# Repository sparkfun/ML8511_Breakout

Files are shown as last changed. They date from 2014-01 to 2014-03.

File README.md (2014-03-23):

ML8511 UV Sensor Breakout
=========================

ML8511 UV Sensor (https://www.sparkfun.com/products/12705)

[*ML8511 UV Sensor (SEN-12705)*](https://www.sparkfun.com/products/12705)

The ML8511 sensor detects ultraviolet light in the 280 to 390nm range.

Repository Contents
-------------------

* **/Firmware** - Example firmware for running the sensor
* **/Hardware** - All Eagle design files (.brd, .sch)
* **/Production** - Test bed files and production panel files
 
License Information
-------------------
The hardware is released under [Creative Commons ShareAlike 4.0 International](https://creativecommons.org/licenses/by-sa/4.0/).
The code is beerware; if you see me (or any other SparkFun employee) at the local, and you've found our code helpful, please buy us a round!

Distributed as-is; no warranty is given.

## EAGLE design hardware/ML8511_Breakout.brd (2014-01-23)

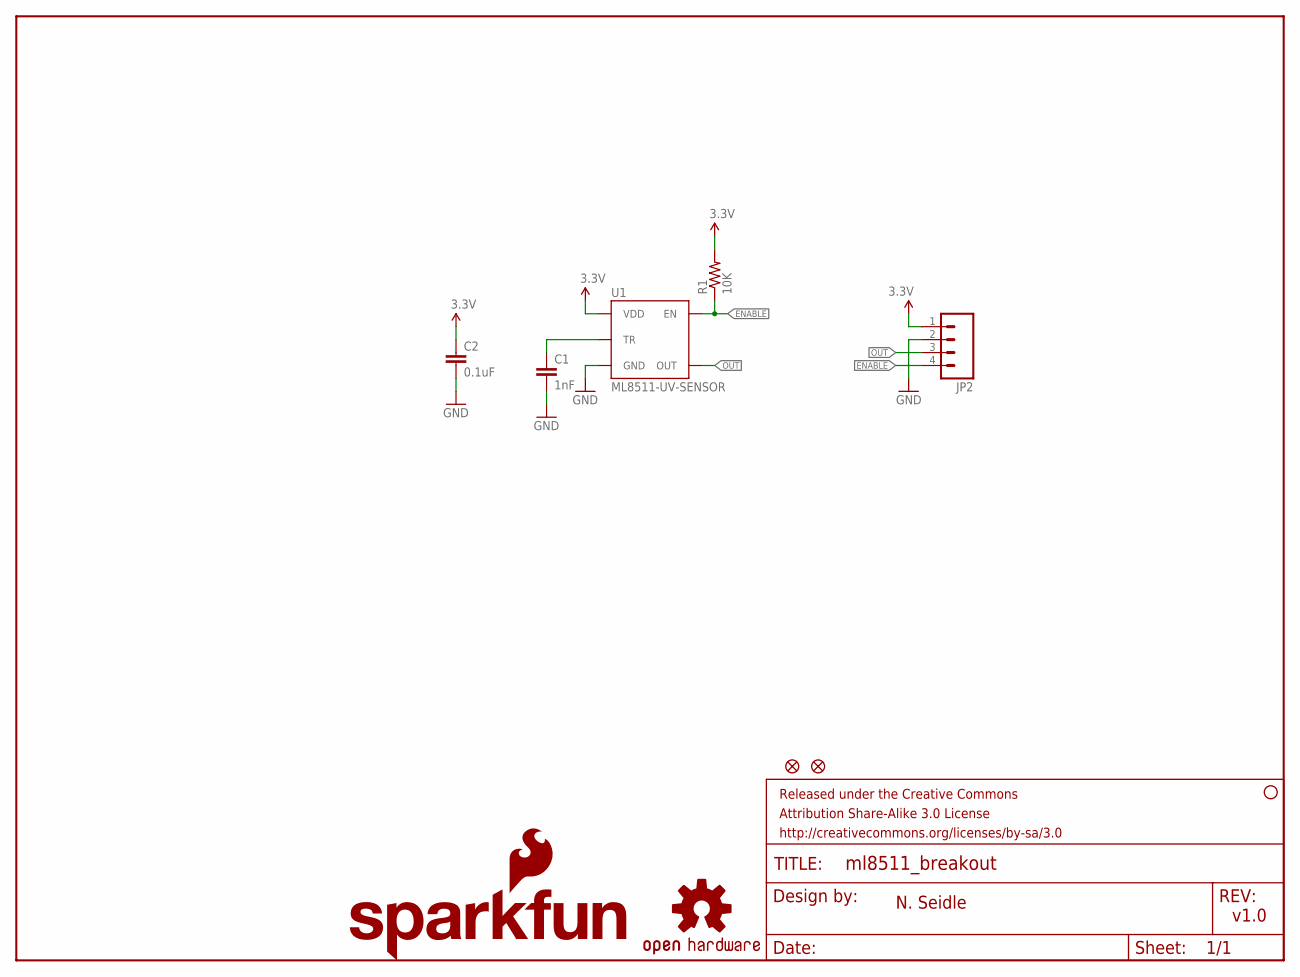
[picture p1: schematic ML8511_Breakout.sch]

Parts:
C1: 1nF; 0603-CAP
C2: 0.1uF; 0603-CAP
FID1, FID2: FIDUCIAL1X2; FIDUCIAL-1X2
FRAME2: FRAME-LETTER; CREATIVE_COMMONS
JP2: M04PTH; 1X04
LOGO2: OSHW-LOGOS; OSHW-LOGO-S
LOGO3: SFE_LOGO_FLAME.1_INCH; SFE_LOGO_FLAME_.1
LOGO4: SFE_LOGO_NAME.1_INCH; SFE_LOGO_NAME_.1
R1: 10K; 0603-RES
STANDOFF1: STAND-OFF
U1: ML8511-UV-SENSOR; ML8511

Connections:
3.3V: C2.1, JP2.1, R1.2, U1.7 (VDD)
ENABLE: JP2.4, R1.1, U1.4 (EN)
GND: C1.2, C2.2, JP2.2, U1.5 (GND)
unnamed: C1.1, U1.10 (TR)
OUT: JP2.3, U1.8 (OUT)

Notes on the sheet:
N. Seidle
v1.0

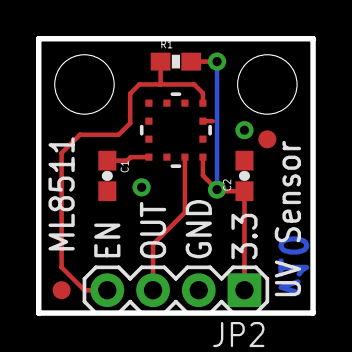
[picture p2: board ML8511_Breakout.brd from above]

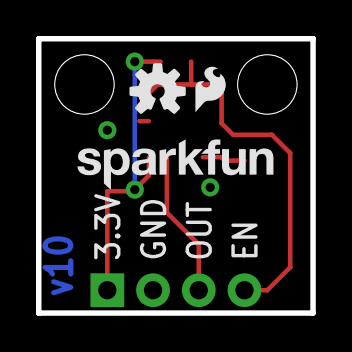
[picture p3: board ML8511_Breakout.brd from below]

Board: 2 copper layers, 15.2 x 15.2 mm, 13 parts (3 on the bottom side), 5 nets.

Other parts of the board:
STANDOFF2: STAND-OFF

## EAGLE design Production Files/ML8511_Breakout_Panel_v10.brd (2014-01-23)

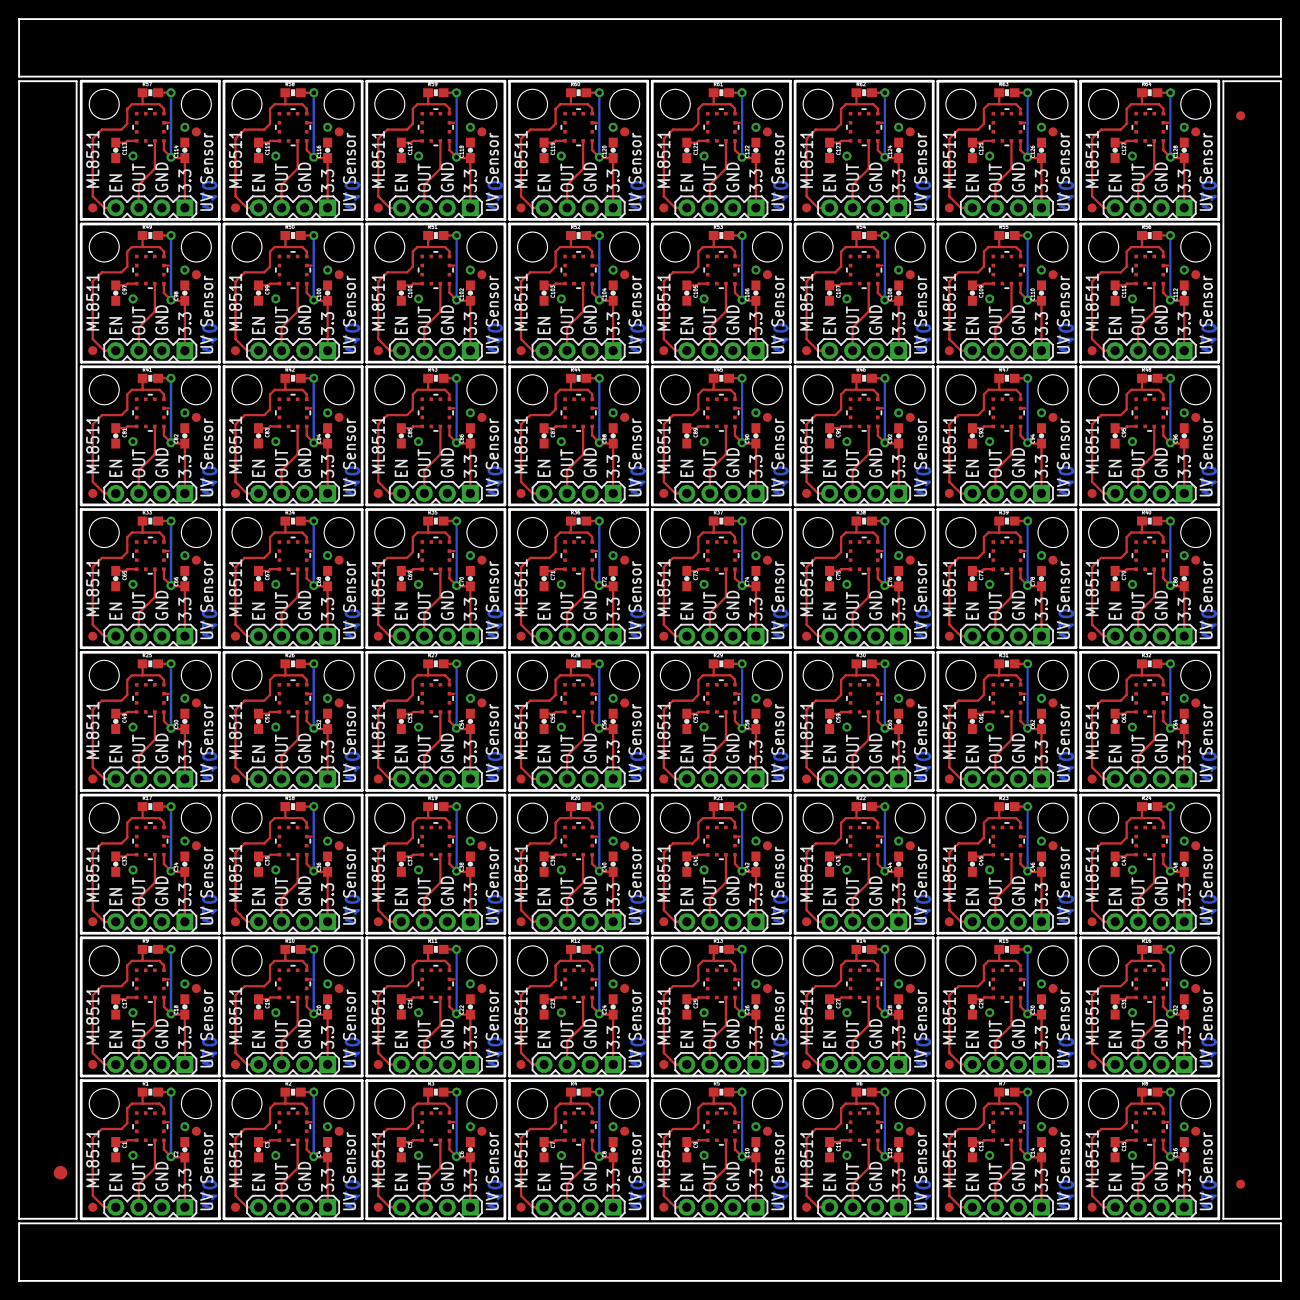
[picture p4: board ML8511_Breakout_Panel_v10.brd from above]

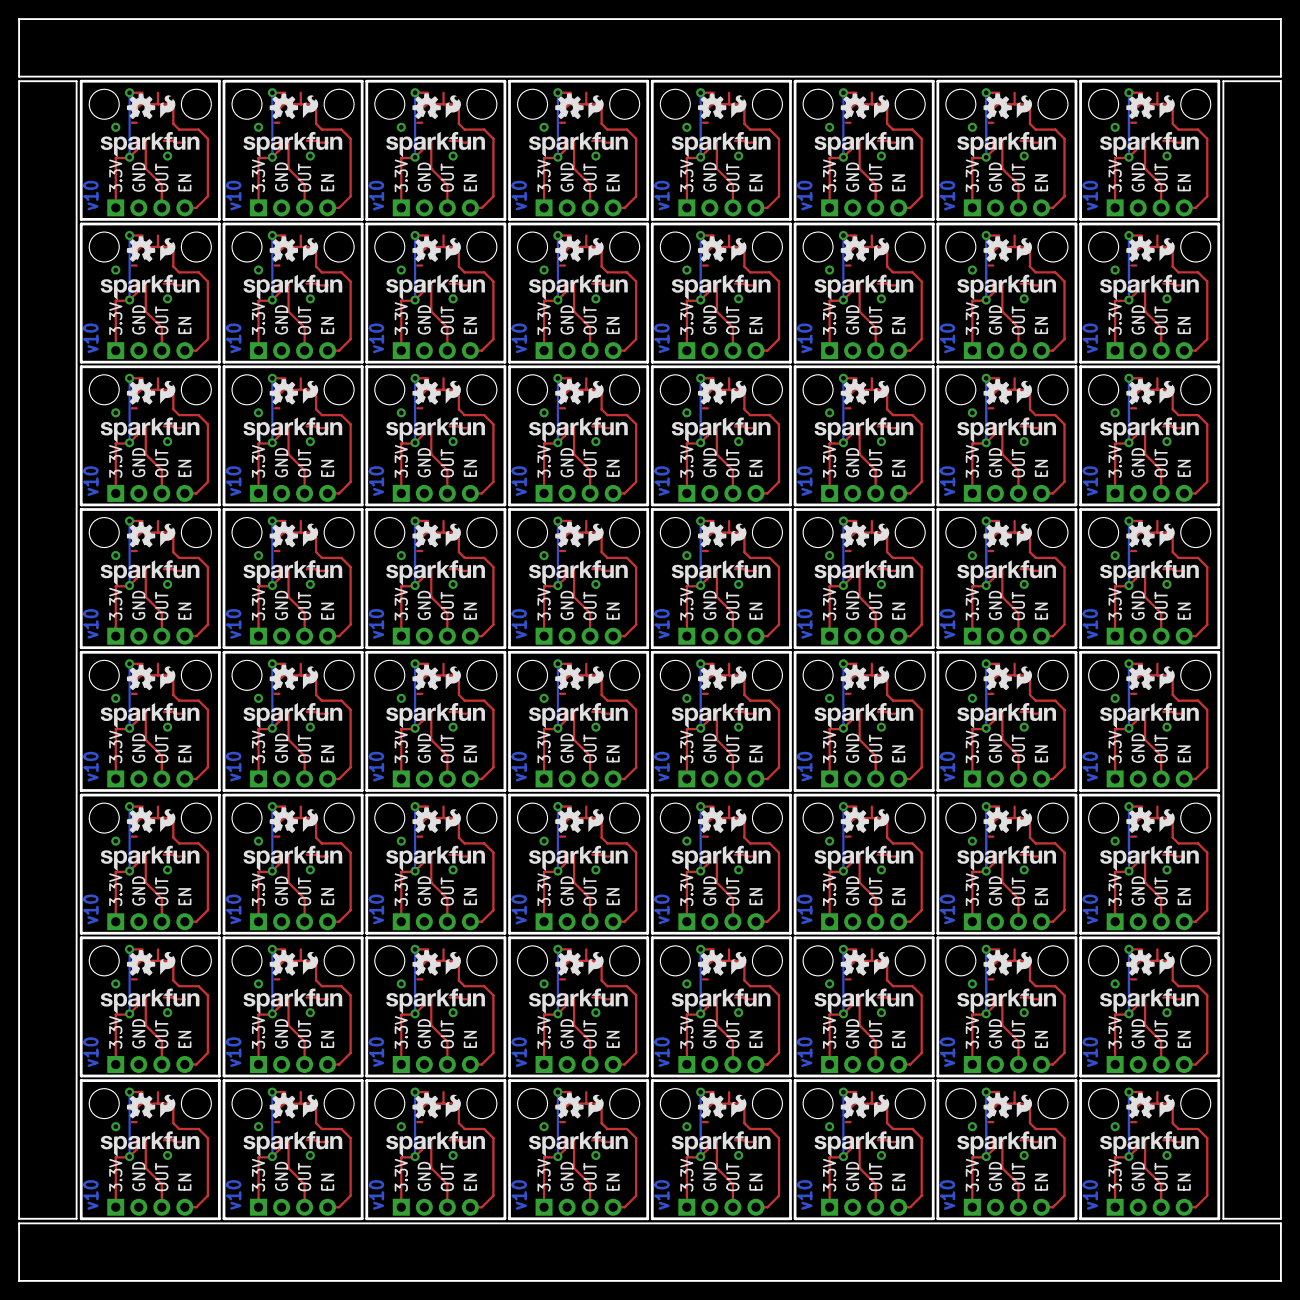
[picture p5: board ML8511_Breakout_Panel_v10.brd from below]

Board: 2 copper layers, 139.2 x 139.2 mm, 771 parts (192 on the bottom side), 320 nets.

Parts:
C1, C3, C5, C7, C9, C11, C13, C15, C17, C19, C21, C23, C25, C27, C29, C31, C33, C35, C37, C39, C41, C43, C45, C47, C49, C51, C53, C55, C57, C59, C61, C63, C65, C67, C69, C71, C73, C75, C77, C79, C81, C83, C85, C87, C89, C91, C93, C95, C97, C99, C101, C103, C105, C107, C109, C111, C113, C115, C117, C119, C121, C123, C125, C127: 1nF; 0603-CAP
C2, C4, C6, C8, C10, C12, C14, C16, C18, C20, C22, C24, C26, C28, C30, C32, C34, C36, C38, C40, C42, C44, C46, C48, C50, C52, C54, C56, C58, C60, C62, C64, C66, C68, C70, C72, C74, C76, C78, C80, C82, C84, C86, C88, C90, C92, C94, C96, C98, C100, C102, C104, C106, C108, C110, C112, C114, C116, C118, C120, C122, C124, C126, C128: 0.1uF; 0603-CAP
E$1: FIDUCIAL-1.5X3
E$4, E$5: FIDUCIAL-1X2
FID1, FID2, FID3, FID4, FID5, FID6, FID7, FID8, FID9, FID10, FID11, FID12, FID13, FID14, FID15, FID16, FID17, FID18, FID19, FID20, FID21, FID22, FID23, FID24, FID25, FID26, FID27, FID28, FID29, FID30, FID31, FID32, FID33, FID34, FID35, FID36, FID37, FID38, FID39, FID40, FID41, FID42, FID43, FID44, FID45, FID46, FID47, FID48, FID49, FID50, FID51, FID52, FID53, FID54, FID55, FID56, FID57, FID58, FID59, FID60, FID61, FID62, FID63, FID64, FID65, FID66, FID67, FID68, FID69, FID70, FID71, FID72, FID73, FID74, FID75, FID76, FID77, FID78, FID79, FID80, FID81, FID82, FID83, FID84, FID85, FID86, FID87, FID88, FID89, FID90, FID91, FID92, FID93, FID94, FID95, FID96, FID97, FID98, FID99, FID100, FID101, FID102, FID103, FID104, FID105, FID106, FID107, FID108, FID109, FID110, FID111, FID112, FID113, FID114, FID115, FID116, FID117, FID118, FID119, FID120, FID121, FID122, FID123, FID124, FID125, FID126, FID127, FID128: FIDUCIAL1X2; FIDUCIAL-1X2
JP1, JP2, JP3, JP4, JP5, JP6, JP7, JP8, JP9, JP10, JP11, JP12, JP13, JP14, JP15, JP16, JP17, JP18, JP19, JP20, JP21, JP22, JP23, JP24, JP25, JP26, JP27, JP28, JP29, JP30, JP31, JP32, JP33, JP34, JP35, JP36, JP37, JP38, JP39, JP40, JP41, JP42, JP43, JP44, JP45, JP46, JP47, JP48, JP49, JP50, JP51, JP52, JP53, JP54, JP55, JP56, JP57, JP58, JP59, JP60, JP61, JP62, JP63, JP64: 1X04
LOGO1, LOGO2, LOGO7, LOGO10, LOGO13, LOGO16, LOGO19, LOGO22, LOGO25, LOGO28, LOGO31, LOGO34, LOGO37, LOGO40, LOGO43, LOGO46, LOGO49, LOGO52, LOGO55, LOGO58, LOGO61, LOGO64, LOGO67, LOGO70, LOGO73, LOGO76, LOGO79, LOGO82, LOGO85, LOGO88, LOGO91, LOGO94, LOGO97, LOGO100, LOGO103, LOGO106, LOGO109, LOGO112, LOGO115, LOGO118, LOGO121, LOGO124, LOGO127, LOGO130, LOGO133, LOGO136, LOGO139, LOGO142, LOGO145, LOGO148, LOGO151, LOGO154, LOGO157, LOGO160, LOGO163, LOGO166, LOGO169, LOGO172, LOGO175, LOGO178, LOGO181, LOGO184, LOGO187, LOGO190: OSHW-LOGOS; OSHW-LOGO-S
LOGO3, LOGO5, LOGO8, LOGO11, LOGO14, LOGO17, LOGO20, LOGO23, LOGO26, LOGO29, LOGO32, LOGO35, LOGO38, LOGO41, LOGO44, LOGO47, LOGO50, LOGO53, LOGO56, LOGO59, LOGO62, LOGO65, LOGO68, LOGO71, LOGO74, LOGO77, LOGO80, LOGO83, LOGO86, LOGO89, LOGO92, LOGO95, LOGO98, LOGO101, LOGO104, LOGO107, LOGO110, LOGO113, LOGO116, LOGO119, LOGO122, LOGO125, LOGO128, LOGO131, LOGO134, LOGO137, LOGO140, LOGO143, LOGO146, LOGO149, LOGO152, LOGO155, LOGO158, LOGO161, LOGO164, LOGO167, LOGO170, LOGO173, LOGO176, LOGO179, LOGO182, LOGO185, LOGO188, LOGO191: SFE_LOGO_FLAME.1_INCH; SFE_LOGO_FLAME_.1
LOGO4, LOGO6, LOGO9, LOGO12, LOGO15, LOGO18, LOGO21, LOGO24, LOGO27, LOGO30, LOGO33, LOGO36, LOGO39, LOGO42, LOGO45, LOGO48, LOGO51, LOGO54, LOGO57, LOGO60, LOGO63, LOGO66, LOGO69, LOGO72, LOGO75, LOGO78, LOGO81, LOGO84, LOGO87, LOGO90, LOGO93, LOGO96, LOGO99, LOGO102, LOGO105, LOGO108, LOGO111, LOGO114, LOGO117, LOGO120, LOGO123, LOGO126, LOGO129, LOGO132, LOGO135, LOGO138, LOGO141, LOGO144, LOGO147, LOGO150, LOGO153, LOGO156, LOGO159, LOGO162, LOGO165, LOGO168, LOGO171, LOGO174, LOGO177, LOGO180, LOGO183, LOGO186, LOGO189, LOGO192: SFE_LOGO_NAME.1_INCH; SFE_LOGO_NAME_.1
R1, R2, R3, R4, R5, R6, R7, R8, R9, R10, R11, R12, R13, R14, R15, R16, R17, R18, R19, R20, R21, R22, R23, R24, R25, R26, R27, R28, R29, R30, R31, R32, R33, R34, R35, R36, R37, R38, R39, R40, R41, R42, R43, R44, R45, R46, R47, R48, R49, R50, R51, R52, R53, R54, R55, R56, R57, R58, R59, R60, R61, R62, R63, R64: 10K; 0603-RES
STANDOFF1, STANDOFF2, STANDOFF3, STANDOFF4, STANDOFF5, STANDOFF6, STANDOFF7, STANDOFF8, STANDOFF9, STANDOFF10, STANDOFF11, STANDOFF12, STANDOFF13, STANDOFF14, STANDOFF15, STANDOFF16, STANDOFF17, STANDOFF18, STANDOFF19, STANDOFF20, STANDOFF21, STANDOFF22, STANDOFF23, STANDOFF24, STANDOFF25, STANDOFF26, STANDOFF27, STANDOFF28, STANDOFF29, STANDOFF30, STANDOFF31, STANDOFF32, STANDOFF33, STANDOFF34, STANDOFF35, STANDOFF36, STANDOFF37, STANDOFF38, STANDOFF39, STANDOFF40, STANDOFF41, STANDOFF42, STANDOFF43, STANDOFF44, STANDOFF45, STANDOFF46, STANDOFF47, STANDOFF48, STANDOFF49, STANDOFF50, STANDOFF51, STANDOFF52, STANDOFF53, STANDOFF54, STANDOFF55, STANDOFF56, STANDOFF57, STANDOFF58, STANDOFF59, STANDOFF60, STANDOFF61, STANDOFF62, STANDOFF63, STANDOFF64, STANDOFF65, STANDOFF66, STANDOFF67, STANDOFF68, STANDOFF69, STANDOFF70, STANDOFF71, STANDOFF72, STANDOFF73, STANDOFF74, STANDOFF75, STANDOFF76, STANDOFF77, STANDOFF78, STANDOFF79, STANDOFF80, STANDOFF81, STANDOFF82, STANDOFF83, STANDOFF84, STANDOFF85, STANDOFF86, STANDOFF87, STANDOFF88, STANDOFF89, STANDOFF90, STANDOFF91, STANDOFF92, STANDOFF93, STANDOFF94, STANDOFF95, STANDOFF96, STANDOFF97, STANDOFF98, STANDOFF99, STANDOFF100, STANDOFF101, STANDOFF102, STANDOFF103, STANDOFF104, STANDOFF105, STANDOFF106, STANDOFF107, STANDOFF108, STANDOFF109, STANDOFF110, STANDOFF111, STANDOFF112, STANDOFF113, STANDOFF114, STANDOFF115, STANDOFF116, STANDOFF117, STANDOFF118, STANDOFF119, STANDOFF120, STANDOFF121, STANDOFF122, STANDOFF123, STANDOFF124, STANDOFF125, STANDOFF126, STANDOFF127, STANDOFF128: STAND-OFF
U1, U2, U3, U4, U5, U6, U7, U8, U9, U10, U11, U12, U13, U14, U15, U16, U17, U18, U19, U20, U21, U22, U23, U24, U25, U26, U27, U28, U29, U30, U31, U32, U33, U34, U35, U36, U37, U38, U39, U40, U41, U42, U43, U44, U45, U46, U47, U48, U49, U50, U51, U52, U53, U54, U55, U56, U57, U58, U59, U60, U61, U62, U63, U64: ML8511-UV-SENSOR; ML8511

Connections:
3.3V: C2.1, JP2.1, R1.2, U1.7
3.3V1: C4.1, JP1.1, R2.2, U2.7
3.3V2: C6.1, JP3.1, R3.2, U3.7
3.3V3: C8.1, JP4.1, R4.2, U4.7
3.3V4: C10.1, JP5.1, R5.2, U5.7
3.3V5: C12.1, JP6.1, R6.2, U6.7
3.3V6: C14.1, JP7.1, R7.2, U7.7
3.3V7: C16.1, JP8.1, R8.2, U8.7
3.3V8: C18.1, JP9.1, R9.2, U9.7
3.3V9: C20.1, JP10.1, R10.2, U10.7
3.3V10: C22.1, JP11.1, R11.2, U11.7
3.3V11: C24.1, JP12.1, R12.2, U12.7
3.3V12: C26.1, JP13.1, R13.2, U13.7
3.3V13: C28.1, JP14.1, R14.2, U14.7
3.3V14: C30.1, JP15.1, R15.2, U15.7
3.3V15: C32.1, JP16.1, R16.2, U16.7
3.3V16: C34.1, JP17.1, R17.2, U17.7
3.3V17: C36.1, JP18.1, R18.2, U18.7
3.3V18: C38.1, JP19.1, R19.2, U19.7
3.3V19: C40.1, JP20.1, R20.2, U20.7
3.3V20: C42.1, JP21.1, R21.2, U21.7
3.3V21: C44.1, JP22.1, R22.2, U22.7
3.3V22: C46.1, JP23.1, R23.2, U23.7
3.3V23: C48.1, JP24.1, R24.2, U24.7
3.3V24: C50.1, JP25.1, R25.2, U25.7
3.3V25: C52.1, JP26.1, R26.2, U26.7
3.3V26: C54.1, JP27.1, R27.2, U27.7
3.3V27: C56.1, JP28.1, R28.2, U28.7
3.3V28: C58.1, JP29.1, R29.2, U29.7
3.3V29: C60.1, JP30.1, R30.2, U30.7
3.3V30: C62.1, JP31.1, R31.2, U31.7
3.3V31: C64.1, JP32.1, R32.2, U32.7
3.3V32: C66.1, JP33.1, R33.2, U33.7
3.3V33: C68.1, JP34.1, R34.2, U34.7
3.3V34: C70.1, JP35.1, R35.2, U35.7
3.3V35: C72.1, JP36.1, R36.2, U36.7
3.3V36: C74.1, JP37.1, R37.2, U37.7
3.3V37: C76.1, JP38.1, R38.2, U38.7
3.3V38: C78.1, JP39.1, R39.2, U39.7
3.3V39: C80.1, JP40.1, R40.2, U40.7
3.3V40: C82.1, JP41.1, R41.2, U41.7
3.3V41: C84.1, JP42.1, R42.2, U42.7
3.3V42: C86.1, JP43.1, R43.2, U43.7
3.3V43: C88.1, JP44.1, R44.2, U44.7
3.3V44: C90.1, JP45.1, R45.2, U45.7
3.3V45: C92.1, JP46.1, R46.2, U46.7
3.3V46: C94.1, JP47.1, R47.2, U47.7
3.3V47: C96.1, JP48.1, R48.2, U48.7
3.3V48: C98.1, JP49.1, R49.2, U49.7
3.3V49: C100.1, JP50.1, R50.2, U50.7
3.3V50: C102.1, JP51.1, R51.2, U51.7
3.3V51: C104.1, JP52.1, R52.2, U52.7
3.3V52: C106.1, JP53.1, R53.2, U53.7
3.3V53: C108.1, JP54.1, R54.2, U54.7
3.3V54: C110.1, JP55.1, R55.2, U55.7
3.3V55: C112.1, JP56.1, R56.2, U56.7
3.3V56: C114.1, JP57.1, R57.2, U57.7
3.3V57: C116.1, JP58.1, R58.2, U58.7
3.3V58: C118.1, JP59.1, R59.2, U59.7
3.3V59: C120.1, JP60.1, R60.2, U60.7
3.3V60: C122.1, JP61.1, R61.2, U61.7
3.3V61: C124.1, JP62.1, R62.2, U62.7
3.3V62: C126.1, JP63.1, R63.2, U63.7
3.3V63: C128.1, JP64.1, R64.2, U64.7
ENABLE: JP2.4, R1.1, U1.4
ENABLE1: JP1.4, R2.1, U2.4
ENABLE2: JP3.4, R3.1, U3.4
ENABLE3: JP4.4, R4.1, U4.4
ENABLE4: JP5.4, R5.1, U5.4
ENABLE5: JP6.4, R6.1, U6.4
ENABLE6: JP7.4, R7.1, U7.4
ENABLE7: JP8.4, R8.1, U8.4
ENABLE8: JP9.4, R9.1, U9.4
ENABLE9: JP10.4, R10.1, U10.4
ENABLE10: JP11.4, R11.1, U11.4
ENABLE11: JP12.4, R12.1, U12.4
ENABLE12: JP13.4, R13.1, U13.4
ENABLE13: JP14.4, R14.1, U14.4
ENABLE14: JP15.4, R15.1, U15.4
ENABLE15: JP16.4, R16.1, U16.4
ENABLE16: JP17.4, R17.1, U17.4
ENABLE17: JP18.4, R18.1, U18.4
ENABLE18: JP19.4, R19.1, U19.4
ENABLE19: JP20.4, R20.1, U20.4
ENABLE20: JP21.4, R21.1, U21.4
ENABLE21: JP22.4, R22.1, U22.4
ENABLE22: JP23.4, R23.1, U23.4
ENABLE23: JP24.4, R24.1, U24.4
ENABLE24: JP25.4, R25.1, U25.4
ENABLE25: JP26.4, R26.1, U26.4
ENABLE26: JP27.4, R27.1, U27.4
ENABLE27: JP28.4, R28.1, U28.4
ENABLE28: JP29.4, R29.1, U29.4
ENABLE29: JP30.4, R30.1, U30.4
ENABLE30: JP31.4, R31.1, U31.4
ENABLE31: JP32.4, R32.1, U32.4
ENABLE32: JP33.4, R33.1, U33.4
ENABLE33: JP34.4, R34.1, U34.4
ENABLE34: JP35.4, R35.1, U35.4
ENABLE35: JP36.4, R36.1, U36.4
ENABLE36: JP37.4, R37.1, U37.4
ENABLE37: JP38.4, R38.1, U38.4
ENABLE38: JP39.4, R39.1, U39.4
ENABLE39: JP40.4, R40.1, U40.4
ENABLE40: JP41.4, R41.1, U41.4
ENABLE41: JP42.4, R42.1, U42.4
ENABLE42: JP43.4, R43.1, U43.4
ENABLE43: JP44.4, R44.1, U44.4
ENABLE44: JP45.4, R45.1, U45.4
ENABLE45: JP46.4, R46.1, U46.4
ENABLE46: JP47.4, R47.1, U47.4
ENABLE47: JP48.4, R48.1, U48.4
ENABLE48: JP49.4, R49.1, U49.4
ENABLE49: JP50.4, R50.1, U50.4
ENABLE50: JP51.4, R51.1, U51.4
ENABLE51: JP52.4, R52.1, U52.4
ENABLE52: JP53.4, R53.1, U53.4
ENABLE53: JP54.4, R54.1, U54.4
ENABLE54: JP55.4, R55.1, U55.4
ENABLE55: JP56.4, R56.1, U56.4
ENABLE56: JP57.4, R57.1, U57.4
ENABLE57: JP58.4, R58.1, U58.4
ENABLE58: JP59.4, R59.1, U59.4
ENABLE59: JP60.4, R60.1, U60.4
ENABLE60: JP61.4, R61.1, U61.4
ENABLE61: JP62.4, R62.1, U62.4
ENABLE62: JP63.4, R63.1, U63.4
ENABLE63: JP64.4, R64.1, U64.4
GND: C1.2, C2.2, JP2.2, U1.5
GND1: C3.2, C4.2, JP1.2, U2.5
GND2: C5.2, C6.2, JP3.2, U3.5
GND3: C7.2, C8.2, JP4.2, U4.5
GND4: C9.2, C10.2, JP5.2, U5.5
GND5: C11.2, C12.2, JP6.2, U6.5
GND6: C13.2, C14.2, JP7.2, U7.5
GND7: C15.2, C16.2, JP8.2, U8.5
GND8: C17.2, C18.2, JP9.2, U9.5
GND9: C19.2, C20.2, JP10.2, U10.5
GND10: C21.2, C22.2, JP11.2, U11.5
GND11: C23.2, C24.2, JP12.2, U12.5
GND12: C25.2, C26.2, JP13.2, U13.5
GND13: C27.2, C28.2, JP14.2, U14.5
GND14: C29.2, C30.2, JP15.2, U15.5
GND15: C31.2, C32.2, JP16.2, U16.5
GND16: C33.2, C34.2, JP17.2, U17.5
GND17: C35.2, C36.2, JP18.2, U18.5
GND18: C37.2, C38.2, JP19.2, U19.5
GND19: C39.2, C40.2, JP20.2, U20.5
GND20: C41.2, C42.2, JP21.2, U21.5
GND21: C43.2, C44.2, JP22.2, U22.5
GND22: C45.2, C46.2, JP23.2, U23.5
GND23: C47.2, C48.2, JP24.2, U24.5
GND24: C49.2, C50.2, JP25.2, U25.5
GND25: C51.2, C52.2, JP26.2, U26.5
GND26: C53.2, C54.2, JP27.2, U27.5
GND27: C55.2, C56.2, JP28.2, U28.5
GND28: C57.2, C58.2, JP29.2, U29.5
GND29: C59.2, C60.2, JP30.2, U30.5
GND30: C61.2, C62.2, JP31.2, U31.5
GND31: C63.2, C64.2, JP32.2, U32.5
GND32: C65.2, C66.2, JP33.2, U33.5
GND33: C67.2, C68.2, JP34.2, U34.5
GND34: C69.2, C70.2, JP35.2, U35.5
GND35: C71.2, C72.2, JP36.2, U36.5
GND36: C73.2, C74.2, JP37.2, U37.5
GND37: C75.2, C76.2, JP38.2, U38.5
GND38: C77.2, C78.2, JP39.2, U39.5
GND39: C79.2, C80.2, JP40.2, U40.5
GND40: C81.2, C82.2, JP41.2, U41.5
GND41: C83.2, C84.2, JP42.2, U42.5
GND42: C85.2, C86.2, JP43.2, U43.5
GND43: C87.2, C88.2, JP44.2, U44.5
GND44: C89.2, C90.2, JP45.2, U45.5
GND45: C91.2, C92.2, JP46.2, U46.5
GND46: C93.2, C94.2, JP47.2, U47.5
GND47: C95.2, C96.2, JP48.2, U48.5
GND48: C97.2, C98.2, JP49.2, U49.5
GND49: C99.2, C100.2, JP50.2, U50.5
GND50: C101.2, C102.2, JP51.2, U51.5
GND51: C103.2, C104.2, JP52.2, U52.5
GND52: C105.2, C106.2, JP53.2, U53.5
GND53: C107.2, C108.2, JP54.2, U54.5
GND54: C109.2, C110.2, JP55.2, U55.5
GND55: C111.2, C112.2, JP56.2, U56.5
GND56: C113.2, C114.2, JP57.2, U57.5
GND57: C115.2, C116.2, JP58.2, U58.5
GND58: C117.2, C118.2, JP59.2, U59.5
GND59: C119.2, C120.2, JP60.2, U60.5
GND60: C121.2, C122.2, JP61.2, U61.5
GND61: C123.2, C124.2, JP62.2, U62.5
GND62: C125.2, C126.2, JP63.2, U63.5
GND63: C127.2, C128.2, JP64.2, U64.5
unnamed: C3.1, U2.10
unnamed: C5.1, U3.10
unnamed: C1.1, U1.10
unnamed: C7.1, U4.10
unnamed: C9.1, U5.10
unnamed: C11.1, U6.10
unnamed: C13.1, U7.10
unnamed: C15.1, U8.10
unnamed: C17.1, U9.10
unnamed: C19.1, U10.10
unnamed: C21.1, U11.10
unnamed: C23.1, U12.10
unnamed: C25.1, U13.10
unnamed: C27.1, U14.10
unnamed: C29.1, U15.10
unnamed: C31.1, U16.10
unnamed: C33.1, U17.10
unnamed: C35.1, U18.10
unnamed: C37.1, U19.10
unnamed: C39.1, U20.10
unnamed: C41.1, U21.10
unnamed: C43.1, U22.10
unnamed: C45.1, U23.10
unnamed: C47.1, U24.10
unnamed: C49.1, U25.10
unnamed: C51.1, U26.10
unnamed: C53.1, U27.10
unnamed: C55.1, U28.10
unnamed: C57.1, U29.10
unnamed: C59.1, U30.10
unnamed: C61.1, U31.10
unnamed: C63.1, U32.10
unnamed: C65.1, U33.10
unnamed: C67.1, U34.10
unnamed: C69.1, U35.10
unnamed: C71.1, U36.10
unnamed: C73.1, U37.10
unnamed: C75.1, U38.10
unnamed: C77.1, U39.10
unnamed: C79.1, U40.10
unnamed: C81.1, U41.10
unnamed: C83.1, U42.10
unnamed: C85.1, U43.10
unnamed: C87.1, U44.10
unnamed: C89.1, U45.10
unnamed: C91.1, U46.10
unnamed: C93.1, U47.10
unnamed: C95.1, U48.10
unnamed: C97.1, U49.10
unnamed: C99.1, U50.10
unnamed: C101.1, U51.10
unnamed: C103.1, U52.10
unnamed: C105.1, U53.10
unnamed: C107.1, U54.10
unnamed: C109.1, U55.10
unnamed: C111.1, U56.10
unnamed: C113.1, U57.10
unnamed: C115.1, U58.10
unnamed: C117.1, U59.10
unnamed: C119.1, U60.10
unnamed: C121.1, U61.10
unnamed: C123.1, U62.10
unnamed: C125.1, U63.10
unnamed: C127.1, U64.10
OUT: JP2.3, U1.8
OUT1: JP1.3, U2.8
OUT2: JP3.3, U3.8
OUT3: JP4.3, U4.8
OUT4: JP5.3, U5.8
OUT5: JP6.3, U6.8
OUT6: JP7.3, U7.8
OUT7: JP8.3, U8.8
OUT8: JP9.3, U9.8
OUT9: JP10.3, U10.8
OUT10: JP11.3, U11.8
OUT11: JP12.3, U12.8
OUT12: JP13.3, U13.8
OUT13: JP14.3, U14.8
OUT14: JP15.3, U15.8
OUT15: JP16.3, U16.8
OUT16: JP17.3, U17.8
OUT17: JP18.3, U18.8
OUT18: JP19.3, U19.8
OUT19: JP20.3, U20.8
OUT20: JP21.3, U21.8
OUT21: JP22.3, U22.8
OUT22: JP23.3, U23.8
OUT23: JP24.3, U24.8
OUT24: JP25.3, U25.8
OUT25: JP26.3, U26.8
OUT26: JP27.3, U27.8
OUT27: JP28.3, U28.8
OUT28: JP29.3, U29.8
OUT29: JP30.3, U30.8
OUT30: JP31.3, U31.8
OUT31: JP32.3, U32.8
OUT32: JP33.3, U33.8
OUT33: JP34.3, U34.8
OUT34: JP35.3, U35.8
OUT35: JP36.3, U36.8
OUT36: JP37.3, U37.8
OUT37: JP38.3, U38.8
OUT38: JP39.3, U39.8
OUT39: JP40.3, U40.8
OUT40: JP41.3, U41.8
OUT41: JP42.3, U42.8
OUT42: JP43.3, U43.8
OUT43: JP44.3, U44.8
OUT44: JP45.3, U45.8
OUT45: JP46.3, U46.8
OUT46: JP47.3, U47.8
OUT47: JP48.3, U48.8
OUT48: JP49.3, U49.8
OUT49: JP50.3, U50.8
OUT50: JP51.3, U51.8
OUT51: JP52.3, U52.8
OUT52: JP53.3, U53.8
OUT53: JP54.3, U54.8
OUT54: JP55.3, U55.8
OUT55: JP56.3, U56.8
OUT56: JP57.3, U57.8
OUT57: JP58.3, U58.8
OUT58: JP59.3, U59.8
OUT59: JP60.3, U60.8
OUT60: JP61.3, U61.8
OUT61: JP62.3, U62.8
OUT62: JP63.3, U63.8
OUT63: JP64.3, U64.8

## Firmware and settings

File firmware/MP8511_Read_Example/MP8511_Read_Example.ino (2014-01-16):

/* 
 MP8511 UV Sensor Read Example
 By: Nathan Seidle
 SparkFun Electronics
 Date: January 15th, 2014
 License: This code is public domain but you buy me a beer if you use this and we meet someday (Beerware license).
 
 The MP8511 UV Sensor outputs an analog signal in relation to the amount of UV light it detects.
 
 Connect the following MP8511 breakout board to Arduino:
 3.3V = 3.3V
 OUT = A0
 GND = GND
 EN = 3.3V
 3.3V = A1
 These last two connections are a little different. Connect the EN pin on the breakout to 3.3V on the breakout.
 This will enable the output. Also connect the 3.3V pin of the breakout to Arduino pin 1.
 
 This example uses a neat trick. Analog to digital conversions rely completely on VCC. We assume
 this is 5V but if the board is powered from USB this may be as high as 5.25V or as low as 4.75V:
 http://en.wikipedia.org/wiki/USB#Power Because of this unknown window it makes the ADC fairly inaccurate
 in most cases. To fix this, we use the very accurate onboard 3.3V reference (accurate within 1%). So by doing an
 ADC on the 3.3V pin (A1) and then comparing this against the reading from the sensor we can extrapolate
 a true-to-life reading no matter what VIN is (as long as it's above 3.4V).
 
 Test your sensor by shining daylight or a UV LED: https://www.sparkfun.com/products/8662

 This sensor detects 280-390nm light most effectively. This is categorized as part of the UVB (burning rays)
 spectrum and most of the UVA (tanning rays) spectrum.
 
 There's lots of good UV radiation reading out there:
 http://www.ccohs.ca/oshanswers/phys_agents/ultravioletradiation.html
 https://www.iuva.org/uv-faqs
 
*/

//Hardware pin definitions
int UVOUT = A0; //Output from the sensor
int REF_3V3 = A1; //3.3V power on the Arduino board

void setup()
{
  Serial.begin(9600);

  pinMode(UVOUT, INPUT);
  pinMode(REF_3V3, INPUT);

  Serial.println("MP8511 example");
}

void loop()
{
  int uvLevel = averageAnalogRead(UVOUT);
  int refLevel = averageAnalogRead(REF_3V3);
  
  //Use the 3.3V power pin as a reference to get a very accurate output value from sensor
  float outputVoltage = 3.3 / refLevel * uvLevel;
  
  float uvIntensity = mapfloat(outputVoltage, 0.99, 2.9, 0.0, 15.0);

  Serial.print("MP8511 output: ");
  Serial.print(uvLevel);

  Serial.print(" MP8511 voltage: ");
  Serial.print(outputVoltage);

  Serial.print(" UV Intensity (mW/cm^2): ");
  Serial.print(uvIntensity);
  
  Serial.println();
  
  delay(100);
}

//Takes an average of readings on a given pin
//Returns the average
int averageAnalogRead(int pinToRead)
{
  byte numberOfReadings = 8;
  unsigned int runningValue = 0; 

  for(int x = 0 ; x < numberOfReadings ; x++)
    runningValue += analogRead(pinToRead);
  runningValue /= numberOfReadings;

  return(runningValue);  
}

//The Arduino Map function but for floats
//From: http://forum.arduino.cc/index.php?topic=3922.0
float mapfloat(float x, float in_min, float in_max, float out_min, float out_max)
{
  return (x - in_min) * (out_max - out_min) / (in_max - in_min) + out_min;
}

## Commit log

2014-01-02 Small changes to layout.
    [ML8511_Breakout.brd]
2014-01-16 Added example sketch. Just an ADC with some ratios and mapping.
    Sensor outputs 1V to 3V. Uses the 3.3V as a reference and maps to
    mW/cm^2.
2014-01-16 DFM Changes
    1.) Modified 3.3V trace so junction is not on IC pad
    2.) Added trestrict under IC
    3.) Routed GND trace directly away from IC
    4.) Modified silk to better incorporate OSHW logo
    5.) Version numbers between sch and brd are now consistent at v10
    [ML8511_Breakout.brd, ML8511_Breakout.sch]
2014-01-16 Minor silk fix
    EN bsilk needed a scoot.
    [ML8511_Breakout.brd]
2014-01-16 Fixed silk error. Updated readme.
    Fixed silk from MP8511 to ML8511.
    [ML8511_Breakout.brd]
2014-01-23 added local fiducials
    [ML8511_Breakout.brd, ML8511_Breakout.sch]
2014-01-23 created panel
    [ML8511_Breakout_Panel_v10.brd]

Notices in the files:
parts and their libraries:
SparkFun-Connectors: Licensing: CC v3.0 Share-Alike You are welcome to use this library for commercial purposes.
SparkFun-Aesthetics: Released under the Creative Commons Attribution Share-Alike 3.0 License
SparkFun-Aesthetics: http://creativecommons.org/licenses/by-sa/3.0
